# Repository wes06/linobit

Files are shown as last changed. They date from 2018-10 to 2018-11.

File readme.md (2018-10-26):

# Linobit
## A core rope ROM device

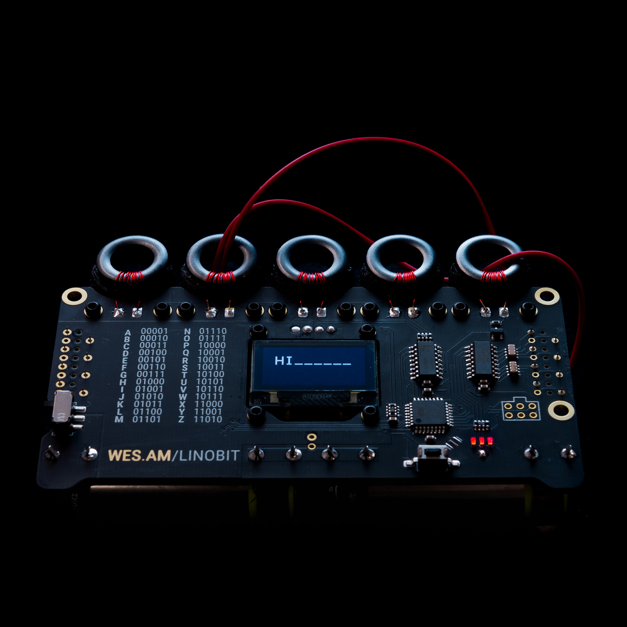
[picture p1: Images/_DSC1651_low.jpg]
First Prototype


<!--img src="./Images/linobit-2018OCT.png"  height="370" align="right"-->

### Table of Contents

 - [Description and Motivation](#description-and-motivation)
 - [How to use it](#how-to-use-it)
 - [Design, Fabrication and Documentation](#design-fabrication-and-documentation)
 - [History and Technical Documentation](#history-and-technical-documentation)
 - [Functional Blocks](#functional-blocks)
 - [References](#references)

### Abstract:

This document goes through the decision making process of designing Linobit, a scaled down and portable version of "Linobyte - A core rope ROM based experiment". From the exploration of the technical aspects of the original core ROM devices from the 60s to the functionality and decisiosn regarding modern circuitry.

#### DESCRIPTION AND MOTIVATION
As computational devices evolve, more tools and interfaces are built between the user and the machine. This allows us to complete increasingly complex tasks without having to focus so much on understanding the nuances of the machine. While this movement is certainly overall positive, one of the drawbacks is that people no longer learn the fundamental processes and concepts which allow the tool to work. Added to that, by neglecting history, we forget the alternatives of the technologies that we use today - forgotten alternatives that maybe once were the status quo. Understanding of those alternatives would give us a broader view of the pros and cons of what we have today, how they superseded their ancestors and what are their pitfalls - important knowledge for those who design possible futures.

Its with these preocupations in mind that Linobyte came into existence. It conciliates the explanation of how bits, bytes and chars work, with a hands on experience of creating Core Rope ROMs: read-only memories that were written by weaving an enameled copper wire through ferrite cores.

### HOW TO USE IT
The whole process is quite straightforward, and the result is immediate: the user can write up to 8 characters. Each character consists of one 5-bit byte. Each core represents one bit, and by weaving the conductive wire through the core center, the user sets a bit as positive. By skipping the core, its set as zero. 

So, if the user wants to write the “A” character, the steps should be the following:

Find out the binary value of the “A” character by checking on the table shown on the PCB: “A” is  00001 in binary.
Figure out which bits have to be set: the first bit on the right.

Weave a wire through the respective coils.

Check the character on the display by pressing the user button and proceed to the next character.

### DESIGN, FABRICATION AND DOCUMENTATION
As important as the device in itself, is the documentation of how it came into existence. The blueprints and schematics not only allow the device to be better understood and even reproduced, but they also give insight into the design decisions that give the object its character.

Documentation was made in three main levels: 

#### 1 - Usage
This gives a brief introduction of how the device is used, and thus a very clear and immediate visualization of cause/effect in core rope ROMs. While this does not provide a technical explanation of how it works, it gives a fast point of correlation for the public in general to start decoding its workings.

#### 2 - Making of
This goes through the process of designing, fabricating and assemblying Linobyte, in a step-by-step, quick and visually enticing manner. For those who had some interest in the device, this provides a bit more background on its construction, and allows for a slow and steady movement into more technical and specific information.

#### 3 - Online repository
This is where the full documentation of Linobyte lies. Descriptions of all the main decisions and the comprimises that were taken or not,  technical and historical references, design files and similar projects.

Those who are really interested in any aspect of the project can find more information here and most likely threads which he/she can follow towards other types of interfaces and memories.

### HISTORY AND TECHNICAL INFORMATION

#### Introduction to Core Rope ROMs

Core Rope Read Only Memories were devices used by computers in the 60s and 70s to store permanent information. They were a fast and robust alternative to other memories of the time (punched cards for example) and were used in historically famous computers such as the AGC - Apollo Guidance Computer. In the case of space bound applications, the ruggedness of Core Rope ROMs against cosmic radiation made them a reliable choice. Despite these positive aspects though, they were extremely labourious to build - the information was encoded through hand winding of an enameled copper wire into ferrite toroids. (It was referred to as "LOL" memory by MIT programmers: Little Old Lady memory). It was such a labourious process that during the development process they had "Core rope ROM Simulators", devices where they would encode the prototypal information to test the final computer.

#### Downsizing Linobyte

Linobyte was developed in the context of Media Archeology class

It features 8 bytes with 8 bits each, which can represent an 8 character word, and therefore is quite relatable to the general public. However, this makes it quite complex and expensive to reproduce, and the multiple functional blocks make it hard to understand in a quick glance. 

In addition, a brute force approach was used in the coil write and read blocks. There is a permanent oscillator on the main board, which drives individual character blocks as soon as they are enabled. This approach was used to allow Linobyte to operate in an assynchronous manner: the pulses of the oscillator are not synched with any set, write or reset operation. This approach allowed for greater flexibility in the design stages: the logic process did not have to be defined yet, and it also helps keep the amount of necessary windings down. The usage of highly integrated modern chips also helped that (I2C GPIO expanders instead of shift registers and latches, etc). 

In essence, while it is a nice illustration of the working principle of the coil and magnetic part of Core Rope ROMs - weave a wire to set a bit - it disregards many of the working principles of the circuitry logic of the time. Also, its complexity and redundant blocks make that the essential aspects of core rope ROM aren't necessarily clear.

Linobit was born to address these issues, striping down unnecessary and redundant power circuits, replacing modern ICs with with more fundamental logic, reducing the amount of coils, and using initially no microcontrollers (this later changed to include an Atmega328, the microcontroller of Arduino Uno, to allow for more hackability by "makers").

In Linobit, since the amount of coils is greatly reduced (from 64 to 5) it is easier to experiment with latches and syncronous execution processes. Therefore, the coil is not driven by an oscillator that is permanently on but instead by a single pulse that is triggered by the press of the button. The pulse then passes through the transformers that have the wire driven through and sets the latches on the secondary side. Instead of the linobyte approach of using a rectifier charging a capacitor - needing multiple pulses to reach the trigger level - the rectifier triggers the SR Latch with a single pulse. (This was the approach used in the Apollo Guidance Computer, as the schematics indicate)

----------------------------------------------------------------------------------------------------------------

#### Number of coils

The number of coils was the first decision for Linobit. While 8 is a nice amout of coils to represent a byte, its more than necessary to represent the concept. 1 is enough to represent the principle of setting a bit, but does not touch that well the process of encoding information. 3 was considered to drive a 3 to 8 decoder and 7 segment display, however when counting, it only goes up to 8, so doesn't represent all the decimal numbers. 4 is enough to represent all decimal numbers but then we are 1 coil away from being able to represent a letter (5 coils - 32 values). So I decided to use 5 coils so that we can store text.

#### Coil read block

As mentioned, a brute force approach was used in driving and reading the coils in Linobyte, so a more elegant and efficient approach was desired. A very desirable solution to read the coils would be a circuitry that receives a fast pulse - so that when driving the coils a single pulse is enough - and whose output can be held high after the pulse is received for a long time - so that the block that after that does not have to be set by a fast and low power pulse. 

An SR Latch does exactly that. It has two inputs, SET and RESET. Whenever the SET receives a high input, it holds the output high until the RESET input is triggered. 

## FUNCTIONAL BLOCKS

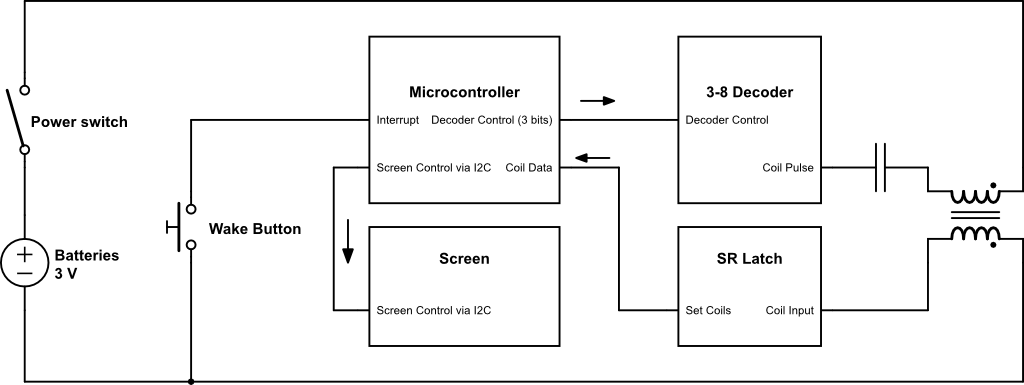
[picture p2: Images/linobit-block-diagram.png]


### Microcontroller

The brain of Linobit, controls all the operations, from driving the coils, to reading the information back and controlling the display. It boots, and goes to sleep. Wake button removes it from sleep, it does its tasks (drive the decoder, reads the coils, sets the display) and goes back to sleep.

### 3-8 Decoder

In order to drive the coils, a 3-8 decoder was chosen (HC138). It allows 3 pins on the microcontroller to control 8 output pins on the decoder. The 3 pins represent 3 bits of a decimal value, the decimal value is the driven pin: 

 - 000 - pin 0 - 0000000H
 - 00H - pin 1 - 000000H0
 - 0H0 - pin 2 - 00000H00
 - 0HH - pin 3 - 0000H000
 - (...)
 - HHH - pin 7 - H0000000

 We use a capacitor in series with the decoder output to prevent it from trying to drive a short-circuit.

### SR Latch

SR stands for SET and RESET, that are the two inputs on this circuit. 

The way an SR Latch works is: as soon as the SET output receives a positive pulse from the cores, its output will stay high until the reset part receives a positive pulse. This allows the microcontroller to read the status of the coils on its own timing instead of having to detect the pulses.

There is only one coil connected to the input of the microcontroller. The microcontroller has 2 interrupts, one for a coil and another for the wake up button. SR Latches com in single, dual, quad packages. So quad SR latch + an interrupt was perfect.

Here follows a breakdown of the signals:

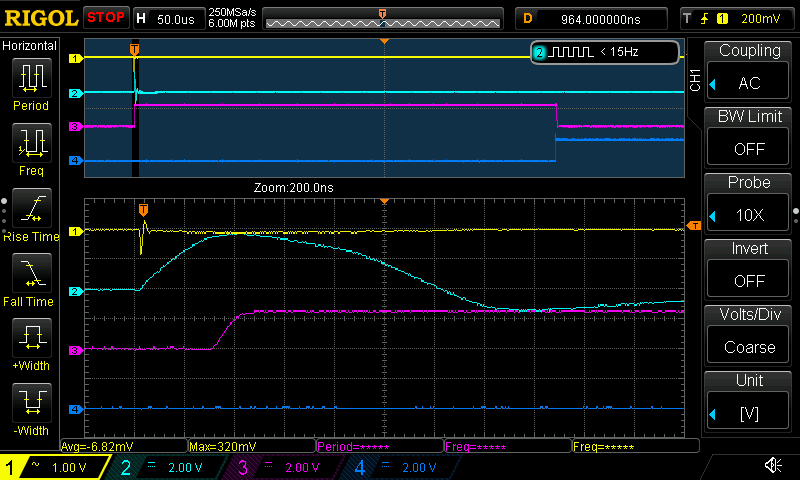
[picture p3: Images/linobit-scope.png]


**Yellow:** The decoder pulses the drive wire through a capacitor.

**Light blue:** Waveform that comes out out of the ferrite toroid coil.

**Purple:** SR Latch gets triggered and maintains the HIGH state long after the pulse was gone.

**Dark Blue:** After the microcontroller reads the coils, it drives the RST signal HIGH, resetting the output of the Latch (Purple)

Note that the pulse (Light blue) takes around 1 micro Second ( ~ 6 horizontal divisions, 200nS each, times six, approx 1.2uS), and the Microcontroller takes about 400 micro Seconds to drive the Reset pulse High. So the scale of speed of the pulse is a lot faster than the microcontroller can handle using normal polling, hence the SR Latch. 

### Display

OLED Display (instead of the 7 segment displays initially planned).

### Power management

Power slider switch and sleeping MCU + wake up button instead of power toggle switch (smaller BOM and easier to assemble on workshops).

### References

MIT Science Reporter—"Computer for Apollo" (1965)
https://www.youtube.com/watch?v=ndvmFlg1WmE

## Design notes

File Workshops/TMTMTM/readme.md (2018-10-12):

# Linobit
## A recreational core rope ROM device

### Descripción:
Linobyte is a core rope memory experiment. It has the goal of teaching basic electronics and programing concepts such as bits and bytes through the construction of an obsolete type of memory.

Visit wes.am/linobyte and wes.am/linobit for more info.

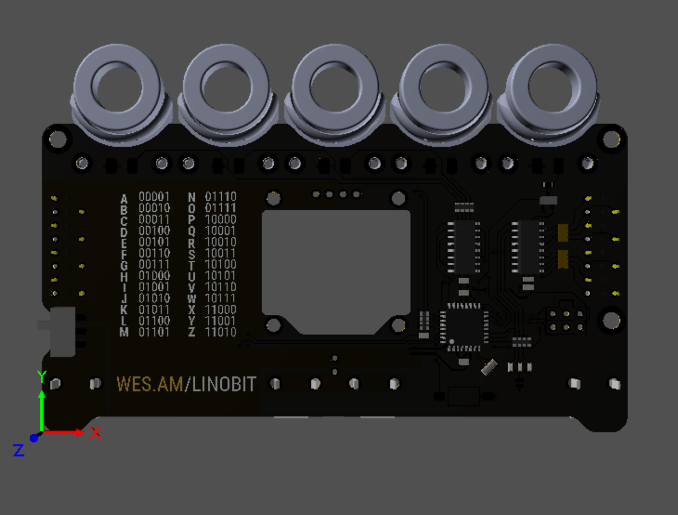
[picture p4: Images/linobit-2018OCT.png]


### Dirigido a:
Makers, beginners and hardware enthusiasts interested in hardware production, media archeology, PCB assembly, Arduino, electronics, etc. 

Soldering, electronics and programming knowledge are not required, however it is important that the participant has decent manual dexterity if she/he wants to build Linobit him/herself. Otherwise I can help with the process.

### Objetivos:

Linobyte has two main objectives:   

1 - introduce basic computation and electronics concepts through a hands on process  

2 - introduce the process of assembly of electronics - from bill of materials, components and blank PCB to uploading the firmware.  

(As a lot of the processes depend a lot on technique, being able to do it in a workshop with an instructor is a lot better than trying to do it alone without the proper techniques and tools. So a large part of the goal is to "break the ice" and make building hardware less intimidating, especially when it comes to SMD components.)

### Duracion:
From 18h00 to 21h00

### Calendario
6, 7 Nov

### Idioma
English

### Precio
N/A

### Programa

#### Day 1
 - Brief introduction to Core Rope ROMs
 - Introduction to the design of Linobyte and Linobit
 - Theoretical information of PCB pasting, population and soldering or reflowing
 - Pasting, populating and soldering (with soldering stations) or reflowing the PCB (via hot air station)

#### Day 2
 - Winding and gluing some coils
 - Hand soldering PTH parts
 - Programming the microcontroller with a pre-made firmware.
 - Playing around with it!

### Imparte

Wesley Lee (BR)

Designer, self-taught in electronics, has years of experience designing and building experiments and experiences such as installations, objects, wearables for artists, brands, educational and industrial applications. Some examples include permanent installations at Google Brazil headquarters and FLAG.CX, his yearly Hardware and Design mentorship at Red Bull Basements Hacker residency, and consultancy services for brazilian mining (Vale S.A.) and sugar industries.

His most recent project, Linobyte, is a mix of media archeology, educational kit and hardware fabrication experiment. It has been featured at Ars Electronica 2018 (Linz, Austria), Push 2018 (Munich, Germany), BestOFF 2018 (Linz, Austria) and TADAEX 2018 (Tehran, Iran).

Due to linobyte's reception, a demand for a more shareable version was created, hence Linobit was born, a workshop-buildable version of Linobyte.

### Tools

Necessary tools from Hangar / TMTMTM - Soldering stations and Hot air stations

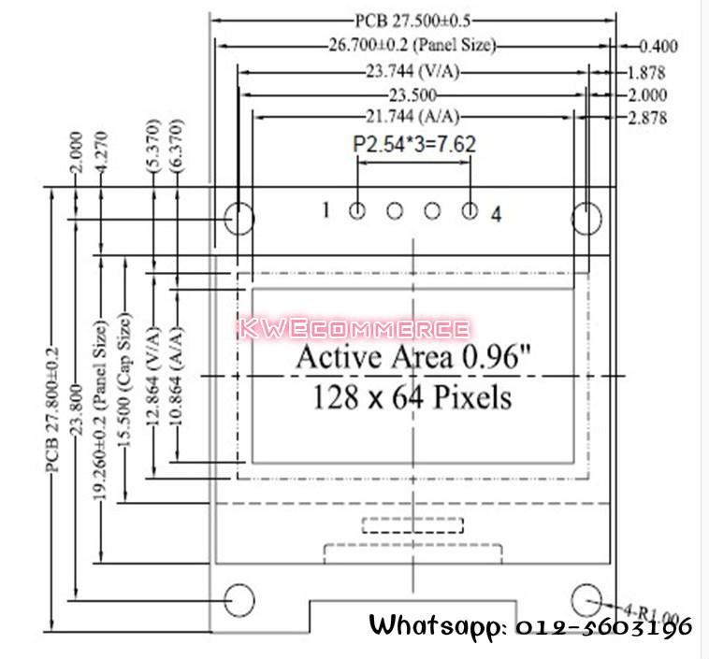
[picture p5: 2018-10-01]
Mechanical/i2c-display/128x64-i2c0.96.jpg

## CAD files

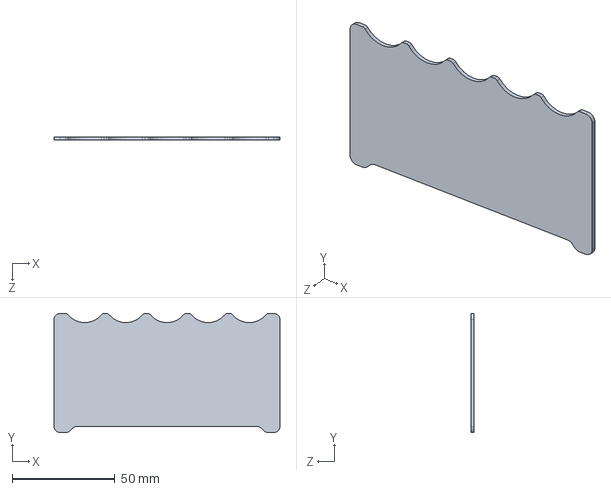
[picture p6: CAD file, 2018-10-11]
Mechanical/linobit-boardShape/linobit-boardShape.SLDPRT
110.0 x 58.0 x 1.60 mm

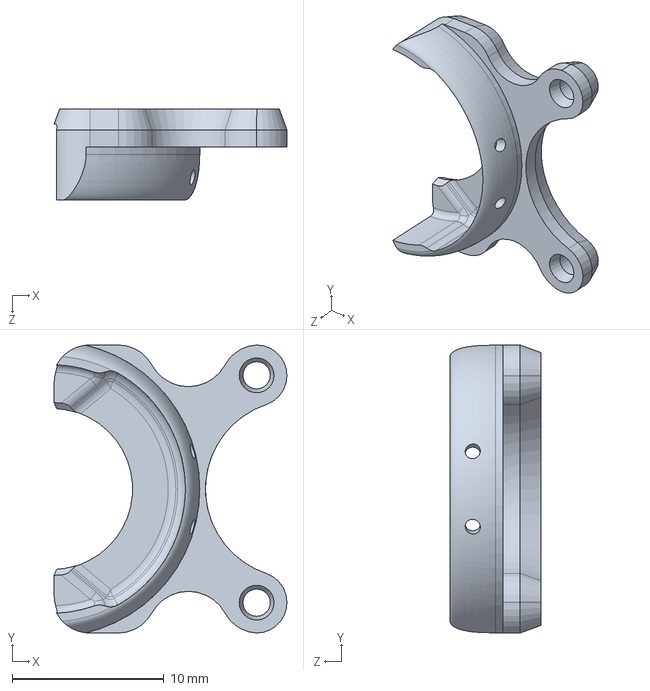
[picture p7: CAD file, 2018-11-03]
Mechanical/Linobit-coilHolder/Linobit-CoilHolder-RevB.SLDPRT
15.4 x 19.0 x 6.00 mm

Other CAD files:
Mechanical/Linobit-coilHolder/Linobit-CoilHolderSketch.SLDPRT
Mechanical/Linobit-coilHolder/Linobit-CoilHolder-RevA.SLDPRT
Mechanical/Linobit-coilHolder/Linobit-CoilHolder-RevA.STL
Mechanical/Linobit-coilHolder/Linobit-CoilHolder-RevB.STL
Mechanical/Linobit-coilHolder/Linobit-CoilHolderSketch.STL
Mechanical/linobit-boardShape/linobit-boardShape.DWG
Mechanical/linobit-boardShape/linobit-boardShape.DXF

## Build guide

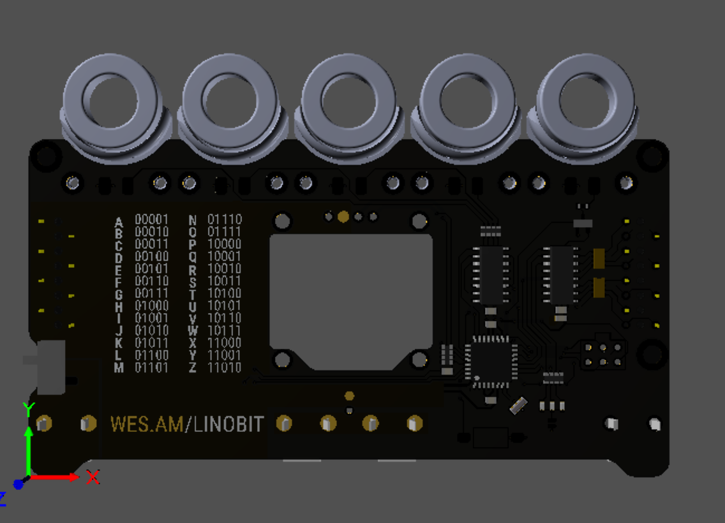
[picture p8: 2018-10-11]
Electronics/linobit-prototype/Project Outputs for linobit/Fabrication/milling-reference.png

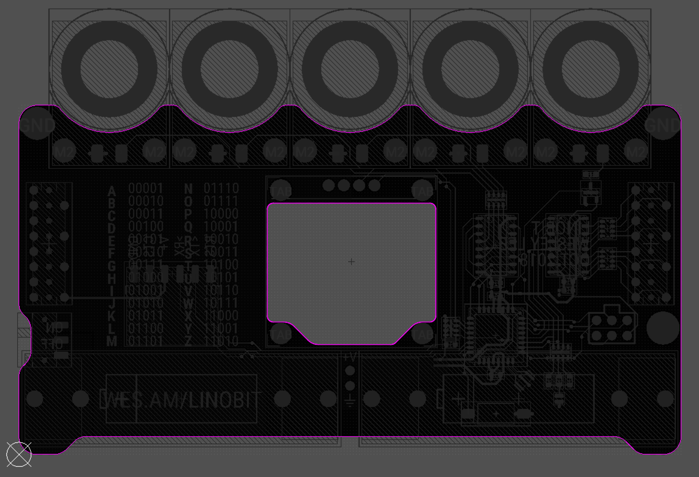
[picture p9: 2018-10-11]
Electronics/linobit-prototype/Project Outputs for linobit/Fabrication/milling-reference-b.png

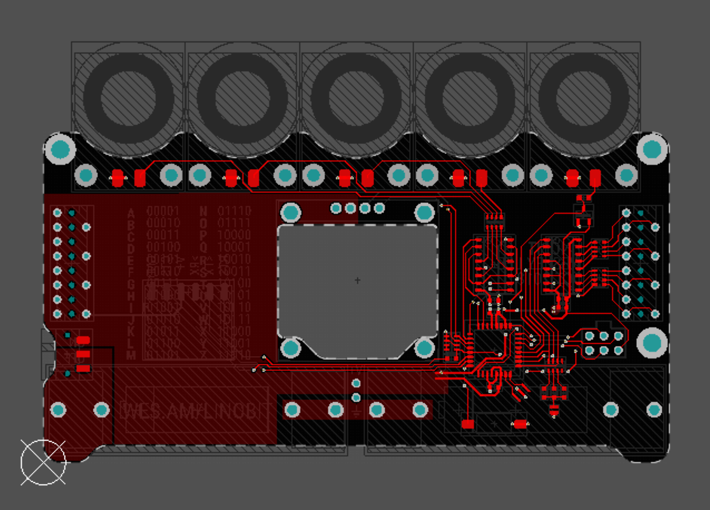
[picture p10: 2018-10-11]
Electronics/linobit-prototype/Project Outputs for linobit/Fabrication/milling-reference-a.png

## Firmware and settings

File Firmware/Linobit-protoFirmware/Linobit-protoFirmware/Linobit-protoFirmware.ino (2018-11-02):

/*

  Firmware for Linobit


  Power managing based on:
  http://www.gammon.com.au/power



  Coil 0      A0
  Coil 1      A1
  Coil 2      A2
  Coil 3      A3
  Coil 4      INT1 / D3
  Latch RST   D10 / PB2

  Decoder EN  D8 / PB0
  Decoder 0 D7 / PD7
  Decoder 1 D6 / PD6
  Decoder 2 D5 / PD5
*/



#include <Arduino.h>
#include <avr/sleep.h>
#include <avr/wdt.h>


#include <Wire.h>

#include <Adafruit_SSD1306.h>
#define OLED_RESET 4
Adafruit_SSD1306 display(OLED_RESET);


bool readCoilsPress = false;


uint8_t sleepLength = 2;

//###############################
//  Char Array
//###############################
//uint8_t charBeingRead = 9;
uint8_t chars[] = {0, 0, 0, 0, 0, 0, 0, 0};

char intToChar[] = {
  '_',
  'A', 'B', 'C', 'D', 'E', 'F', 'G', 'H',
  'I', 'J', 'K', 'L', 'M', 'N', 'O', 'P',
  'Q', 'R', 'S', 'T', 'U', 'V', 'W', 'X',
  'Y', 'Z'
};



//###############################
//  Coil 5 Interrupt
//###############################
bool coil5 = false;
void coil5interrupt() {
  coil5 = true;
}



//###############################
//  Wake Func
//###############################
void wake ()
{
  readCoilsPress = true;
  sleep_disable(); // cancel sleep as a precaution
  detachInterrupt (0); // precautionary while we do other stuff
}



//###############################
//  Sleep Func
//###############################
void goToSleep(uint8_t _mode) {

  if (_mode == 1) {

    // clear various "reset" flags
    MCUSR = 0;
    // allow changes, disable reset
    WDTCSR = bit (WDCE) | bit (WDE);
    // set interrupt mode and an interval
    WDTCSR = bit (WDIE) | bit (WDP1) | bit (WDP2) | bit (WDP3);// | bit (WDP1) | bit (WDP2);

    wdt_reset();  // pat the dog

    MCUCR = bit (BODS) | bit (BODSE);
    MCUCR = bit (BODS);

  }


  set_sleep_mode (SLEEP_MODE_PWR_DOWN);
  sleep_enable();

  // Do not interrupt before we go to sleep, or the
  // ISR will detach interrupts and we won't wake.
  noInterrupts ();
  pinMode(2, INPUT_PULLUP);

  // will be called when pin D2 goes low
  attachInterrupt (0, wake, FALLING);
  EIFR = bit (INTF0);  // clear flag for interrupt 0


  // We are guaranteed that the sleep_cpu call will be done
  // as the processor executes the next instruction after
  // interrupts are turned on.
  interrupts ();  // one cycle
  sleep_cpu ();   // one cycle
}





//###############################
//  Set decoder outputs
//###############################
void setDecoder(uint8_t _decode) {
  if (_decode == 0b100) _decode = 001;
  else if (_decode == 0b001) _decode = 100;
  else if (_decode == 0b110) _decode = 0b011;
  else if (_decode == 0b011) _decode = 0b110;


  PORTD = (_decode << 5);
  PORTB &= ~_BV(PB0); // LOW - enable decoder
  PORTB |= _BV(PB0); // HIGH - disable decoder
}


//###############################
//  Read the coils and return
//###############################
uint8_t readCoils() {

  int _charSum = 0;

  _charSum = 0;

  //chars[_charBeingRead] = PINC & 0b00001111;

  _charSum += digitalRead(A0) * 16;
  _charSum += digitalRead(A1) * 8;
  _charSum += digitalRead(A2) * 4;
  _charSum += digitalRead(A3) * 2;


  if (coil5) {
    _charSum += 1;
    coil5 = false;
  }

  //reset Latch
  PORTB |= _BV(PB2); // digitalWrite(10, HIGH);
  delay(1);
  PORTB &= ~_BV(PB2); //digitalWrite(10, LOW);

  return _charSum;
}




//###############################
//  Setup IO
//###############################
void setupIO() {

  pinMode(2, INPUT_PULLUP); // button interrupt pull-up

  pinMode(8, OUTPUT);
  digitalWrite(8, HIGH); // disable 3-8 decoder

  pinMode(A0, INPUT); // coil inputs
  pinMode(A1, INPUT); // coil inputs
  pinMode(A2, INPUT); // coil inputs
  pinMode(A3, INPUT); // coil inputs

  pinMode(10, OUTPUT);
  digitalWrite(10, LOW); // disable RS Latch reset

  pinMode(5, OUTPUT); // decoder outputs
  pinMode(6, OUTPUT); // decoder outputs
  pinMode(7, OUTPUT); // decoder outputs

  attachInterrupt (1, coil5interrupt, RISING);

}

//###############################
//  Watchdog Interrupt
//###############################
ISR (WDT_vect)
{
  wdt_disable();  // disable watchdog
}  // end of WDT_vect



//###############################
//  Runs on boot
//###############################
void setup ()
{
  // by default, we'll generate the high voltage from the 3.3v line internally! (neat!)
  display.begin(SSD1306_SWITCHCAPVCC, 0x3C);  // initialize with the I2C addr 0x3D (for the 128x64)

  display.clearDisplay();
  display.setTextSize(1);
  display.setTextColor(WHITE);
  display.setCursor(16, 24);
  display.setTextSize(2);
  display.println(" LINOBIT");
  display.display();



  // disable ADC
  ADCSRA = 0;

  setupIO();


  delay(200);
  readCoilsPress = true;
  //goToSleep(0);
}




//###############################
//  Runs everytime it wakes
//###############################
bool showDisplay = true;


void loop ()
{
  // this is used if only one char is to be read per wake up
  //  charBeingRead++;
  //  if (charBeingRead >= 8) {
  //    charBeingRead = 0;
  //    display.clearDisplay();
  //    display.setCursor(16, 16);
  //  }

  if (readCoilsPress) {
    for (uint8_t charBeingRead = 0; charBeingRead < 8; charBeingRead++) {
      setDecoder(charBeingRead); // drive the decoder
      chars[charBeingRead] = readCoils();

    }
  }


  display.clearDisplay();
  display.setCursor(16, 16);

  if (showDisplay) {
    showDisplay = false;
    if (readCoilsPress) {
      for (uint8_t charBeingRead = 0; charBeingRead < 8; charBeingRead++) {
        display.print(intToChar[chars[charBeingRead]]);
        display.display();
      }
      readCoilsPress = false;
    }
    else {
      for (uint8_t charBeingRead = 0; charBeingRead < 8; charBeingRead++) {
        display.print(intToChar[chars[charBeingRead]]);
      }
      display.display();
    }
    sleepLength = 2;
  }
  else {
    showDisplay = true;
    sleepLength = 2;
    display.display();
  }

  goToSleep(1); // go back to sleep
}

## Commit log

2018-10-01 Rough schematics and layout
    [linobit-PCB.PcbDoc, linobit-coilInputs.SchDoc, linobit.PrjPCB]
2018-10-01 i2c screen initial reference
2018-10-02 Sketch of PCB Shape
    [linobit-boardShape.DWG, linobit-boardShape.SLDPRT]
2018-10-11 First iteration sent to Fab
    [Copy of linobit-PCB.PcbDoc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]
2018-10-11 Board shape
    [linobit-boardShape.DXF, linobit-boardShape.SLDPRT]
2018-10-31 Decoder flipped and variables cleaned up
    [Linobit-protoFirmware.ino]
2018-11-02 Coil Holder
    [Linobit-CoilHolder-RevA.SLDPRT, Linobit-CoilHolder-RevA.STL, Linobit-CoilHolderSketch.SLDPRT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]
2018-11-02 Holder modified to accommodate 30 turns.
    [Linobit-CoilHolder-RevB.SLDPRT, Linobit-CoilHolder-RevB.STL]
2018-11-02 Animation with sleep intervals for battery saving added
2018-11-03 Model adjusted for print - 1 hole removed and softer edges
    [Linobit-CoilHolder-RevB.SLDPRT, Linobit-CoilHolder-RevB.STL]
